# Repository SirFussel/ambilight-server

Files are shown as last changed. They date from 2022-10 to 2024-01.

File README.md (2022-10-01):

# Custom Ambilight using Raspberry Pi 3
## Hardware
- Raspberry Pi 3 or higher
- USB framegrabber
- WS2801 LED stripes
- HDPC compatible HDMI splitter
- Power supply
- Wires and cables
## Software
- Hyperion
## Additional Features
- Temperature controlled case using fan
- Blind service to disable the stripes when TV is off
## Pi Configuration
### WIFI configuration
1. Add following lines to ```/etc/network/interfaces``` in order to disable WIFI power save mode:
    ```
    allow-hotplug wlan0
    iface wlan0 inet manual
    post-up iw wlan0 set power_save off
    ```
2. Make sure ```/etc/wpa_supplicant/wpa_supplicant.conf``` looks similar to this and replace the placeholders:
    ```
    ctrl_interface=DIR=/var/run/wpa_supplicant GROUP=netdev
    update_config=1
    country=DE

    network={
            ssid="<ssid>"
            psk="<password>"
    }
    ```
    You can do this by using ```sudo wpa_passphrase "<ssid>" "<password>" >> /etc/wpa_supplicant/wpa_supplicant.conficant.conf``` instead of manually adding it to the file.
3. Restart WIFI by using ```sudo ifconfig wlan0 down``` and ```sudo ifconfig wlan0 up``` afterwards.
### Add services
1. Add a file to ```/etc/systems/system/``` folder and make sure its extension is ```.service```. Its content looks similar to:
    ```
    [Unit]
    Description=Temperature control service
    After=multi-user.target
    [Service]
    Type=simple
    Restart=always
    ExecStart=/usr/bin/python3 /home/pi/tempcontrol.py
    [Install]
    WantedBy=multi-user.target
    ```
2. Register the service using ```sudo service enable <servicename>.service```
3. Run the service using ```sudo service start <servicename>.service```

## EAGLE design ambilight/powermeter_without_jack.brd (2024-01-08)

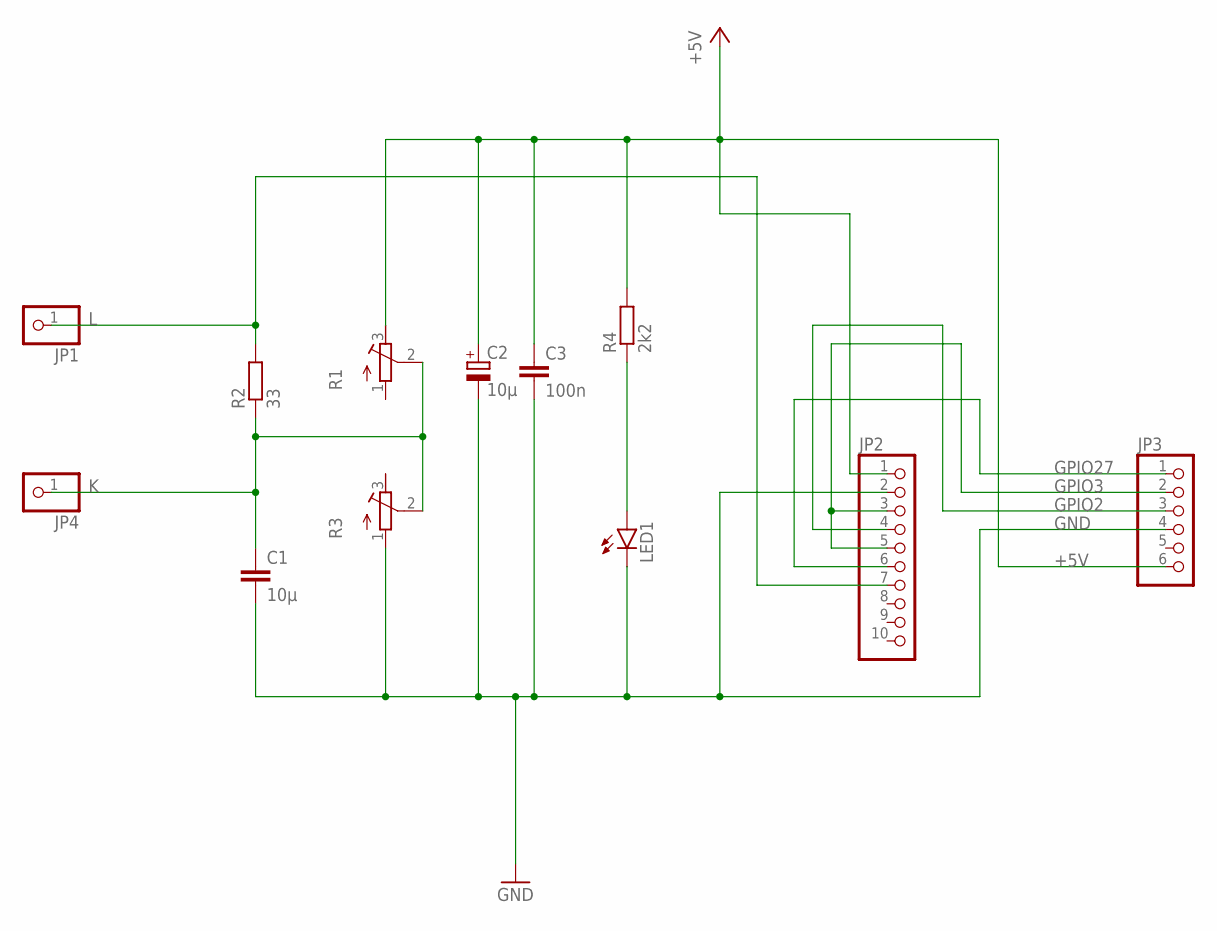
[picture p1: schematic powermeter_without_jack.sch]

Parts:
C1: 10µ; C075-052X106
C2: 10µ; E5-5
C3: 100n; C050-025X075
JP1, JP4: PINHD-1X1; 1X01
JP2: PINHD-1X10; 1X10
JP3: PINHD-1X6; 1X06
LED1: LED3MM
R1, R3: R-TRIMM3296W; RTRIM3296W
R2: 33; 0411/15
R4: 2k2; 0207/10

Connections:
+5V: C2.+, C3.1, JP2.1, JP3.6, R1.3 (E), R4.2
GND: C1.2, C2.-, C3.2, JP2.2, JP3.4, LED1.K (C), R3.1 (A)
GPIO2: JP2.4, JP3.3
GPIO3: JP2.3, JP2.5, JP3.2
GPIO27: JP2.6, JP3.1
K: C1.1, JP4.1, R1.2 (S), R2.1, R3.2 (S)
L: JP1.1, JP2.7, R2.2
unnamed: LED1.A, R4.1

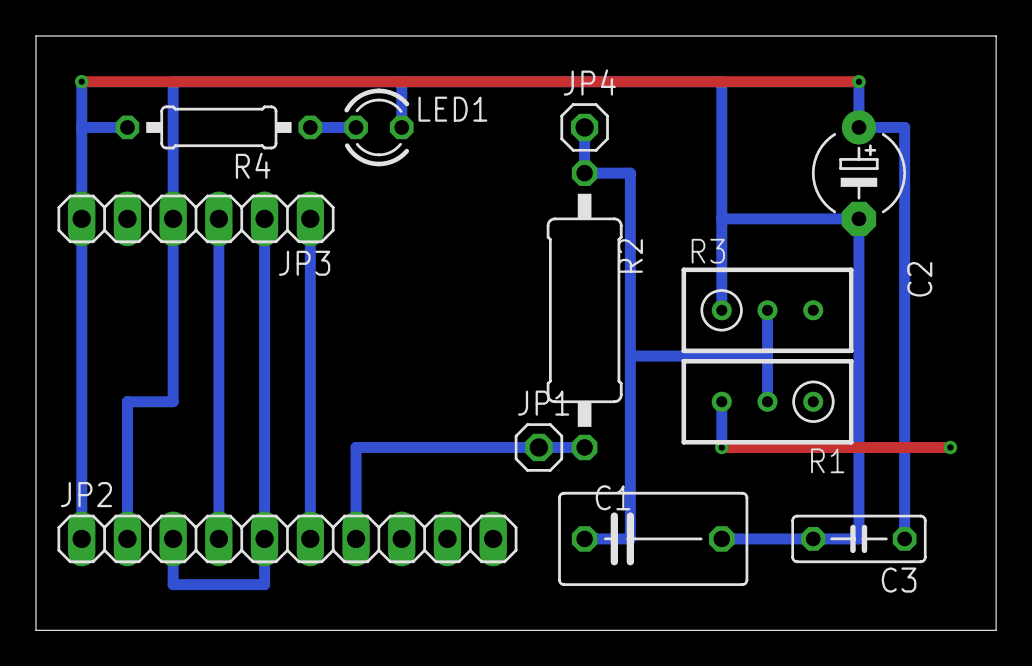
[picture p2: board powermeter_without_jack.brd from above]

Board: 2 copper layers, 53.3 x 33.0 mm, 12 parts (0 on the bottom side), 8 nets.

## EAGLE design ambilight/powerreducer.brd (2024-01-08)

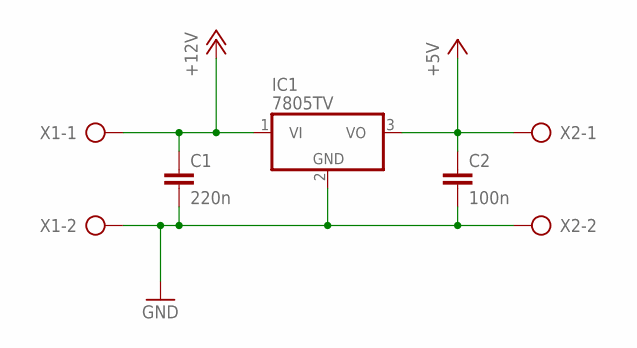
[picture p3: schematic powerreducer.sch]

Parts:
C1: 220n; C050-025X075
C2: 100n; C050-025X075
IC1: 7805TV; TO220V
X1, X2: AK300/2

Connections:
+5V: C2.1, IC1.3 (VO), X2.1
+12V: C1.1, IC1.1 (VI), X1.1
GND: C1.2, C2.2, IC1.2 (GND), X1.2, X2.2

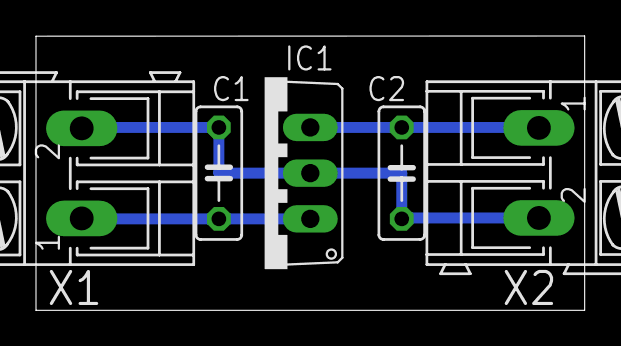
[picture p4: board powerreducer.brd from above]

Board: 2 copper layers, 30.5 x 15.2 mm, 5 parts (0 on the bottom side), 3 nets.

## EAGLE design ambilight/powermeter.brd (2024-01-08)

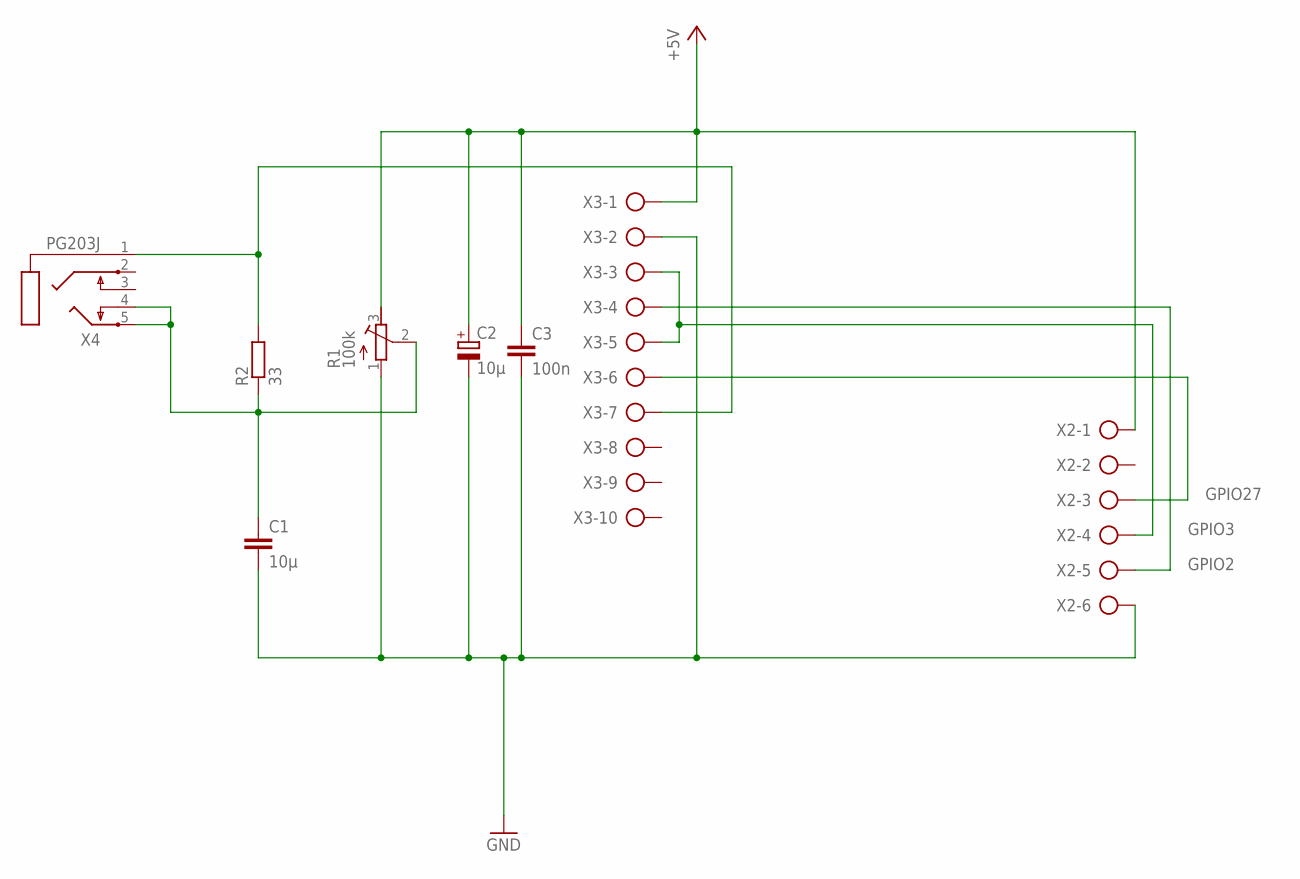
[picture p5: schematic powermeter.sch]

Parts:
C1: 10µ; C050-025X075
C2: 10µ; E5-10,5
C3: 100n; C050-025X075
R1: 100k; RTRIM64W
R2: 33; 0309/12
X2: AK300/6
X3: AK300/10
X4: PG203J

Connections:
+5V: C2.+, C3.1, R1.3 (E), X2.1, X3.1
GND: C1.2, C2.-, C3.2, R1.1 (A), X2.6, X3.2
GPIO2: X2.5, X3.4
GPIO3: X2.4, X3.3, X3.5
GPIO27: X2.3, X3.6
unnamed: R2.2, X3.7, X4.1
unnamed: C1.1, R1.2 (S), R2.1, X4.4, X4.5

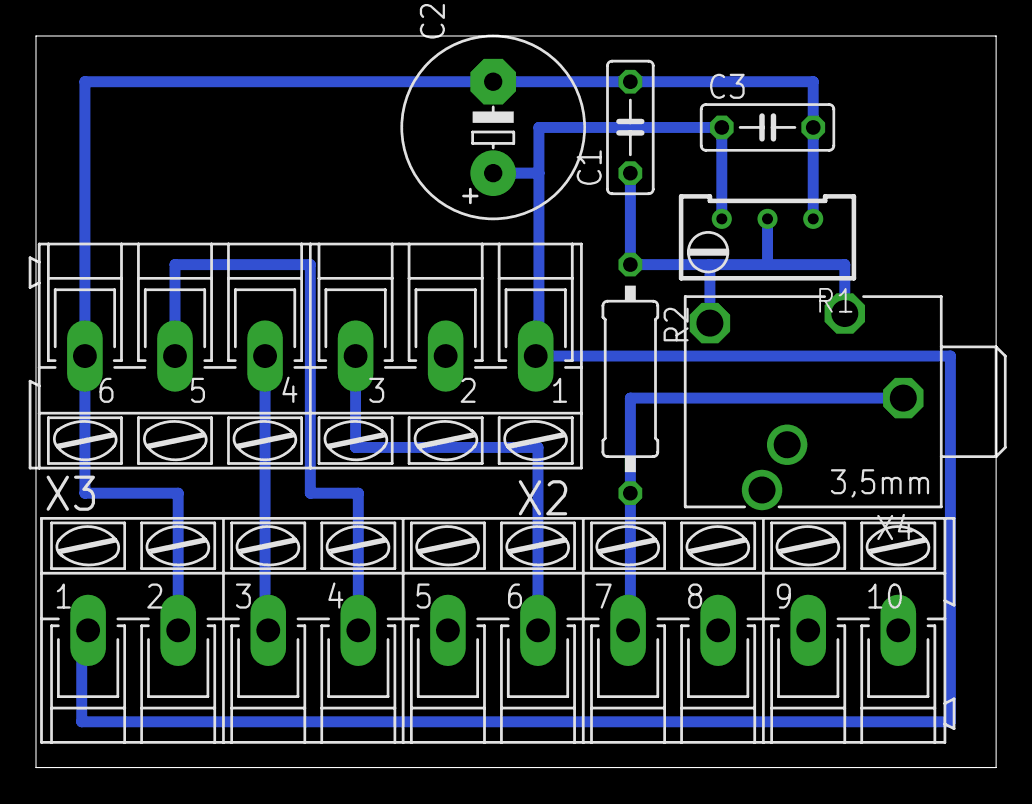
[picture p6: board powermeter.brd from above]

Board: 2 copper layers, 53.3 x 40.6 mm, 8 parts (0 on the bottom side), 7 nets.

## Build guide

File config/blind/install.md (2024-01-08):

#### Blind Service
Properly connect the ADC to I2C.

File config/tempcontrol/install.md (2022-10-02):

#### Tempcontrol Service
Make sure to properly wire the fan driver to GPIO pin 17.

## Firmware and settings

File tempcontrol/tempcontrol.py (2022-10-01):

#!/usr/bin/python3
import RPi.GPIO as GPIO
import re
import os
import logging
from datetime import datetime
import sys
import time
import signal


class GracefulKiller:
    """
    https://stackoverflow.com/questions/18499497/how-to-process-sigterm-signal-gracefully/31464349#31464349
    """
    def __init__(self):
        self.kill_now = False
        signal.signal(signal.SIGINT, self.exit_gracefully)
        signal.signal(signal.SIGTERM, self.exit_gracefully)

    def exit_gracefully(self, *args):
        self.kill_now = True


class TemperatureControl:
    def __init__(self, write_logs: bool = False):
        self._killer = GracefulKiller()

        self.TEMP_UPPER_LIMIT_CELSIUS = 55.0
        self.TEMP_LOWER_LIMIT_CELSIUS = 45.0

        self.cpu_temp: float = 0.0
        self.last_cpu_temp: float = 0.0
        self.logger = logging.getLogger()
        self.logger.setLevel(logging.DEBUG)

        stdout_handler = logging.StreamHandler(sys.stdout)
        formatter = logging.Formatter("%(asctime)s - %(levelname)s - %(message)s")
        stdout_handler.setFormatter(formatter)
        self.logger.addHandler(stdout_handler)

        if write_logs:
            log_dir = os.path.join(os.getcwd(), "logs")
            os.makedirs(log_dir, exist_ok=True)
            timestamp = datetime.now().strftime("%y-%m-%d_%H-%M-%S")
            log_location = os.path.join(log_dir, f"{timestamp}.log")
            output_file_handler = logging.FileHandler(log_location)
            output_file_handler.setFormatter(formatter)
            self.logger.addHandler(output_file_handler)
            self.logger.info(f"Writing logs to {log_location}")
        else:
            self.logger.info("Writing logs disabled")
        self.logger.info("Configuring board settings")
        self.fan_pin = 17
        self.fan_enabled = False
        GPIO.setmode(GPIO.BCM)
        GPIO.setup(self.fan_pin, GPIO.OUT)

    def get_temperature(self) -> float:
        try:
            cpu_temp_str = os.popen("vcgencmd measure_temp").readline()
            return float(re.sub(r"[^0-9.]+", "", cpu_temp_str))
        except Exception as e:
            self.logger.exception("An error occurred while reading temperature:", exc_info=e)

    def enable_fan(self):
        try:
            GPIO.output(self.fan_pin, True)
            self.fan_enabled = True
            self.logger.info("Fan enabled")
        except Exception as e:
            self.logger.exception("Failed to enable fan:", exc_info=e)

    def disable_fan(self):
        try:
            GPIO.output(self.fan_pin, False)
            self.fan_enabled = False
            self.logger.info("Fan disabled")
        except Exception as e:
            self.logger.exception("Failed to enable fan:", exc_info=e)

    def run(self):
        try:
            while not self._killer.kill_now:
                self.last_cpu_temp = self.cpu_temp
                self.cpu_temp = self.get_temperature()
                self.logger.info(f"Current cpu temperature {self.cpu_temp} \'C")
                if self.cpu_temp >= self.TEMP_UPPER_LIMIT_CELSIUS:
                    if not self.fan_enabled:
                        self.logger.info(f"Temperature limit of {self.TEMP_UPPER_LIMIT_CELSIUS} \'C exceeded")
                        self.enable_fan()
                elif self.cpu_temp <= self.TEMP_LOWER_LIMIT_CELSIUS:
                    if self.fan_enabled:
                        self.logger.info(f"Temperature fell below limit of {self.TEMP_LOWER_LIMIT_CELSIUS} \'C")
                        self.disable_fan()
                time.sleep(1)
        except KeyboardInterrupt:
            self.logger.info("User requested exit.")
            sys.exit(0)
        except Exception as e:
            self.logger.exception("Unhandled error:", exc_info=e)
        finally:
            GPIO.cleanup()


if __name__ == "__main__":
    tc = TemperatureControl()
    tc.run()

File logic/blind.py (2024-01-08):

import time
import threading
from base import GracefulKiller
import board
import busio
import adafruit_ads1x15.ads1015 as ADS
from adafruit_ads1x15.analog_in import AnalogIn


class BlindService:
    def __init__(self) -> None:
        # Create the I2C bus
        self.i2c = busio.I2C(board.SCL, board.SDA)
        # Create the ADC object using the I2C bus
        self.ads = ADS.ADS1015(self.i2c)
        # Create single-ended input on channel 0
        self.chan = AnalogIn(self.ads, ADS.P0)

        self._worker = threading.Thread(target=self._poll, daemon=True)
        self._worker.start()
        
    def _poll(self):
        print("{:>5}\t{:>5}".format('raw', 'v'))
        while True:
            print("{:>5}\t{:>5.3f}".format(self.chan.value, self.chan.voltage))
            time.sleep(0.5)

# observer did not block
print("no block")
killer = GracefulKiller()

while not killer.kill_now:
    time.sleep(0.1)

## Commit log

2022-10-02 Disabled fan on startup
2024-01-08 Added new technique to check the TVs power status
    [powermeter.brd, powermeter.sch, powermeter_without_jack.brd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]
